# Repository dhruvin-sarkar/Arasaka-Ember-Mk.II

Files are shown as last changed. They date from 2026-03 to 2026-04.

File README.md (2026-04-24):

# Ember Mk.II — Flexible LED Watch

A cyberpunk-inspired wristwatch built on a custom flexible PCB, wrapping high-density alphanumeric LED displays around the wrist in an infinite loop. Displays animated effects and real-time clock output.

---

## What is it?

Ember Mk.II is a handmade wristwatch built around a custom flexible PCB that wraps 14 Broadcom HCMS-2901 alphanumeric LED displays around the wrist.

## How to use it

Press the center button to wake the display and trigger the boot animation. Use the up and down buttons to cycle through menus: time display, mini time, brightness, current, timezone offset, and wave mode. The watch charges and programs over the same 4-pin header used as the wrist. To set the time, send a Unix epoch timestamp over serial.

---

## PCB Layout

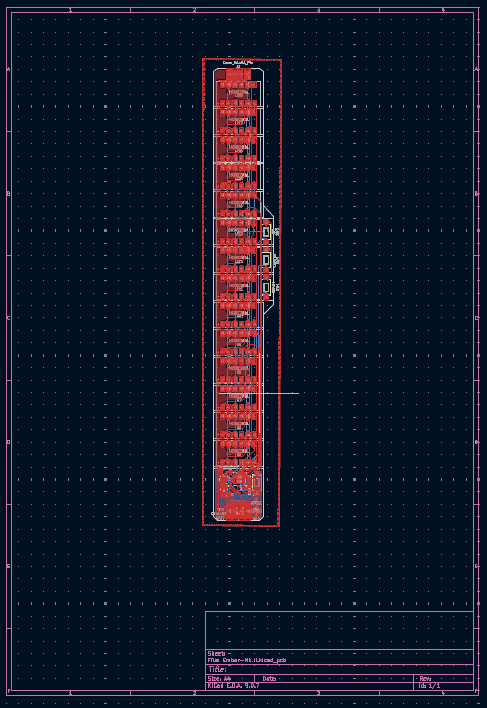
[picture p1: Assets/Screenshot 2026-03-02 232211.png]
PCB Layout


| Top Layer | Bottom Layer | All Layers |
|---|---|---|
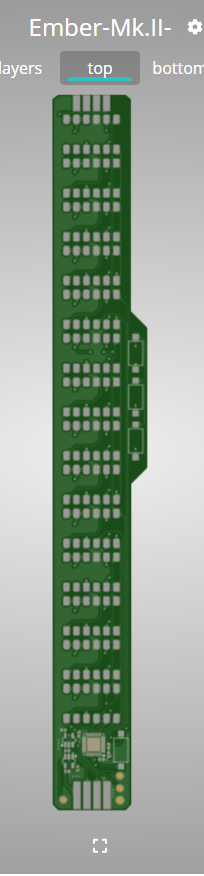
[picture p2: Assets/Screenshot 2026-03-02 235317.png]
Top
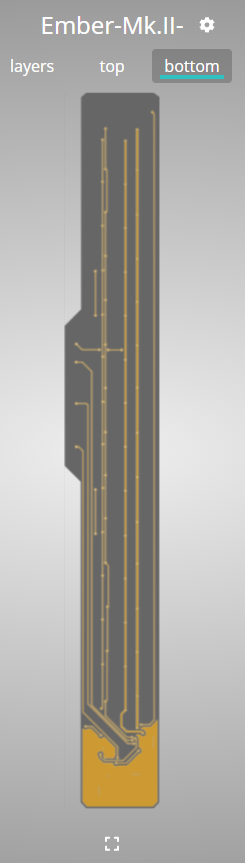
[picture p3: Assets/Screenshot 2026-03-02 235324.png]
Bottom
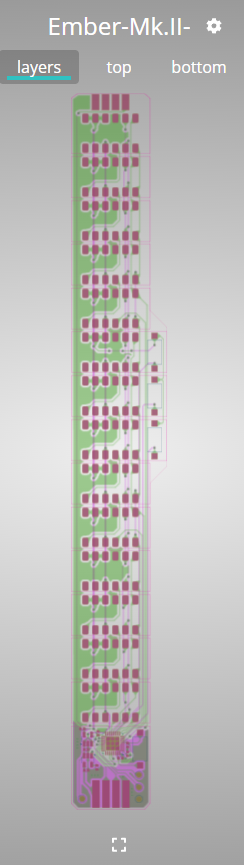
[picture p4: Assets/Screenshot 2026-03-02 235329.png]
Layers
|  |  |  |

---

## Schematic

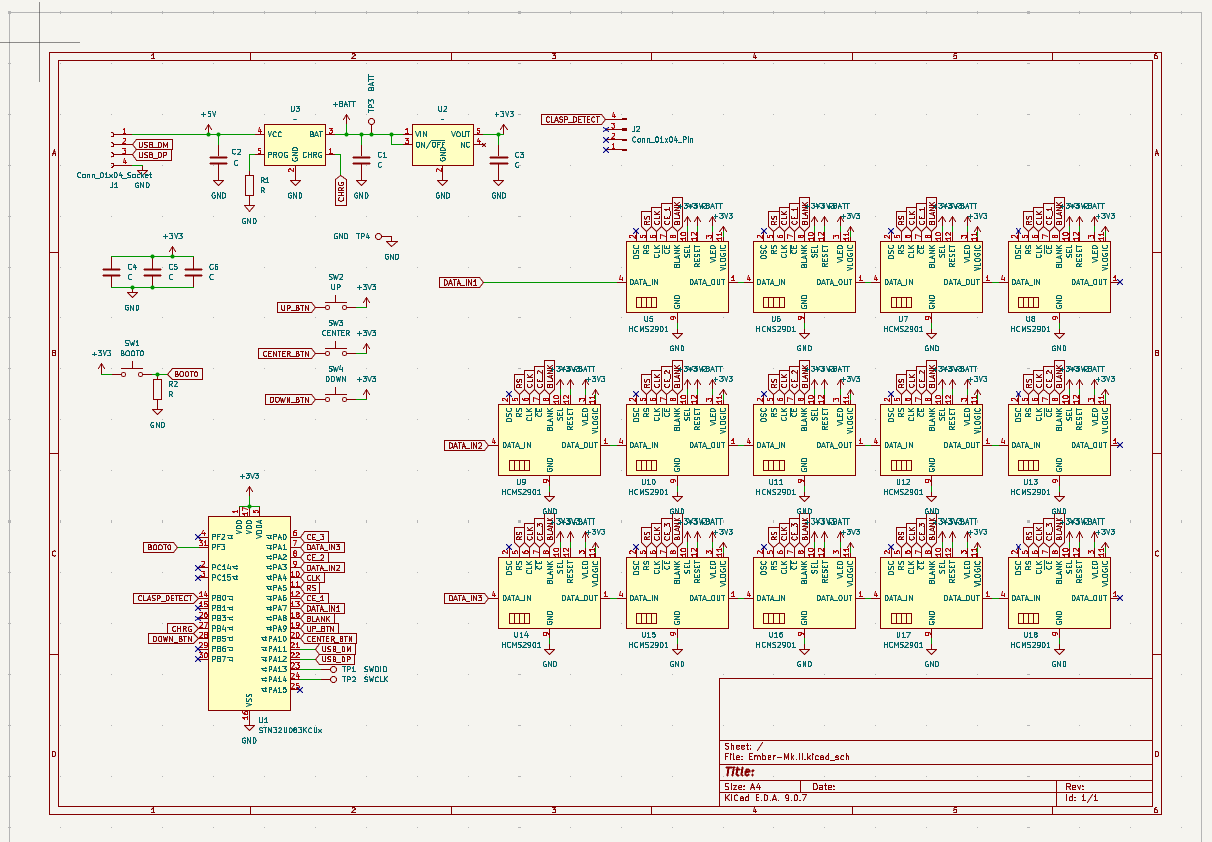
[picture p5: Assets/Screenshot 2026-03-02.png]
Schematic


---

## Bill of Materials

| Ref | Component | Value / Part | Package | Qty | Datasheet / Source |
|-----|---|---|---|-----|---|
| U5–U18 | Alphanumeric LED Display | **HCMS-3901** | Custom SMD (bent TH pins) | 14 | [Broadcom Datasheet](https://docs.broadcom.com/doc/AV02-0683EN) · [Mouser](https://www.mouser.com/ProductDetail/Broadcom-Avago/HCMS-3901) |
| U1 | Microcontroller | **STM32U083KCUx** | QFN-32 | 1 | [ST Datasheet](https://www.st.com/resource/en/datasheet/stm32u083kc.pdf) · [Mouser](https://www.mouser.com/ProductDetail/STMicroelectronics/STM32U083KCU6) |
| U2 | LDO Regulator | **LP2980** (3.3V fixed) | SOT-23-5 | 1 | [TI Datasheet](https://www.ti.com/lit/ds/symlink/lp2980.pdf) · [Mouser](https://www.mouser.com/ProductDetail/Texas-Instruments/LP2980IM5X-3.3) |
| U3 | LiPo Charger | **STC4054** | SOT-23-5 | 1 | [Datasheet](https://datasheet.lcsc.com/lcsc/2210211830_Shenzhen-Fuman-Elec-STC4054_C89852.pdf) · [LCSC](https://www.lcsc.com/product-detail/Battery-Management_Shenzhen-Fuman-Elec-STC4054_C89852.html) |
| J1 | Wrist clasp socket | 4-pin SMD socket | custom:SMD_2.54_1x04_LONG | 1 | Standard 2.54mm pin header |
| J2 | Wrist clasp pin | 4-pin SMD pin | custom:SMD_2.54_1x04_SHORT | 1 | Standard 2.54mm pin header |
| SW1 | Boot mode button | BOOT0 | PTS636 | 1 | [C&K PTS636 Datasheet](https://www.ckswitches.com/media/1471/pts636.pdf) · [Mouser](https://www.mouser.com/ProductDetail/CK/PTS636-SK25-SMTR-LFS) |
| SW2 | Up button | UP | PTS636 | 1 | [C&K PTS636 Datasheet](https://www.ckswitches.com/media/1471/pts636.pdf) |
| SW3 | Center button | CENTER | PTS636 | 1 | [C&K PTS636 Datasheet](https://www.ckswitches.com/media/1471/pts636.pdf) |
| SW4 | Down button | DOWN | PTS636 | 1 | [C&K PTS636 Datasheet](https://www.ckswitches.com/media/1471/pts636.pdf) |
| R1, R2 | Resistor | TBD | 0402 | 2 | Standard 0402 SMD resistor |
| TP1 | Test point | SWDIO | D1.5mm pad | 1 | SWD debug interface |
| TP2 | Test point | SWCLK | D1.5mm pad | 1 | SWD debug interface |
| TP3 | Test point | BATT | D1.5mm pad | 1 | Battery voltage monitor |
| TP4 | Test point | GND | D1.5mm pad | 1 | Ground reference |

> ⚠️ **Display availability note:** The HCMS-2901 is a discontinued Broadcom part. Stock availability varies — check Mouser, DigiKey, and secondary markets. Expect ~$25–35 per unit. The HCMS-3901 is a pin-compatible alternative.

---

## Firmware & Dependencies

Display control is based on a modified version of the HCMS39xx Arduino library:
> https://github.com/Andy4495/HCMS39xx

Modifications include:
- `printDirectBufferOverlay()` — bitwise OR compositing for animation over UI
- `printDirectBufferXOR()` — XOR compositing for blinking effects
- `refreshDisplay()` — decoupled buffer writes from display refresh for frame timing

To compile:
- Install **STM32Duino** (Arduino core for STM32): [https://github.com/stm32duino/Arduino_Core_STM32](https://github.com/stm32duino/Arduino_Core_STM32)
- Install **STM32RTC** library: [https://github.com/stm32duino/STM32RTC](https://github.com/stm32duino/STM32RTC)
- Target board: **STM32U08 series** (Generic STM32U0)

---

## Resources

| Resource | Link |
|---|---|
| STM32U083 Reference Manual | [ST.com](https://www.st.com/resource/en/reference_manual/rm0503-stm32u0-series-advanced-armbased-32bit-mcus-stmicroelectronics.pdf) |
| HCMS-2901 Application Brief | [Broadcom](https://docs.broadcom.com/doc/5988-7539EN) |
| STM32Duino Core | [GitHub](https://github.com/stm32duino/Arduino_Core_STM32) |
| STM32RTC Library | [GitHub](https://github.com/stm32duino/STM32RTC) |
| HCMS39xx Arduino Library (base) | [GitHub](https://github.com/Andy4495/HCMS39xx) |
| KiCad EDA | [kicad.org](https://www.kicad.org) |

---

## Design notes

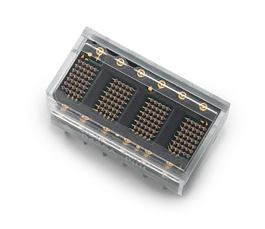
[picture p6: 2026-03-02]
Assets/Screenshot 2026-03-03 001525.png

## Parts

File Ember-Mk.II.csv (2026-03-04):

Reference | Value | Datasheet | Footprint | Qty | DNP
C1,C2,C3,C4,C5,C6 | C | ~ | Capacitor_SMD:C_0402_1005Metric | 6
J1 | Conn_01x04_Socket | ~ | custom:SMD_2.54_1x04_LONG | 1
J2 | Conn_01x04_Pin | ~ | custom:SMD_2.54_1x04_SHORT | 1
R1,R2 | R | ~ | Resistor_SMD:R_0402_1005Metric | 2
SW1 | BOOT0 | ~ | custom:PTS636 | 1
SW2 | UP | ~ | custom:PTS636 | 1
SW3 | CENTER | ~ | custom:PTS636 | 1
SW4 | DOWN | ~ | custom:PTS636 | 1
TP1 | SWDIO | ~ | TestPoint:TestPoint_Pad_D1.5mm | 1
TP2 | SWCLK | ~ | TestPoint:TestPoint_Pad_D1.5mm | 1
TP3 | BATT | ~ | TestPoint:TestPoint_Pad_D1.5mm | 1
TP4 | GND | ~ | TestPoint:TestPoint_Pad_D1.5mm | 1
U1 | STM32U083KCUx | https://www.st.com/resource/en/datasheet/stm32u083kc.pdf | Package_DFN_QFN:QFN-32-1EP_5x5mm_P0.5mm_EP3.45x3.45mm | 1
U2,U3 | ~ |  | Package_TO_SOT_SMD:SOT-23-5 | 2
U5,U6,U7,U8,U9,U10,U11,U12,U13,U14,U15,U16,U17,U18 | HCMS2901 |  | custom:HCMS2901_SMD | 14

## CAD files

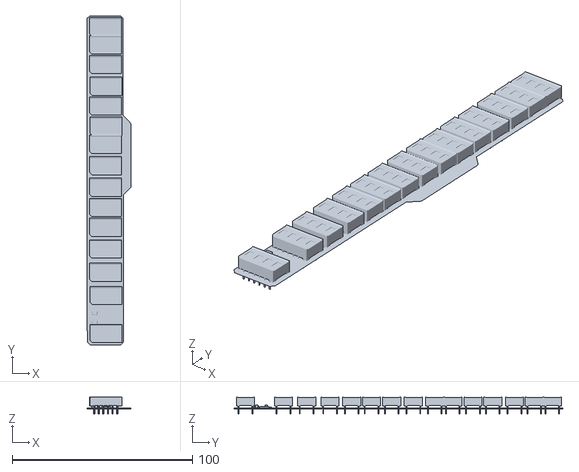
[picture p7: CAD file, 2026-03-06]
Arasaka Mock Render.stl
24.3 x 182.3 x 9.40

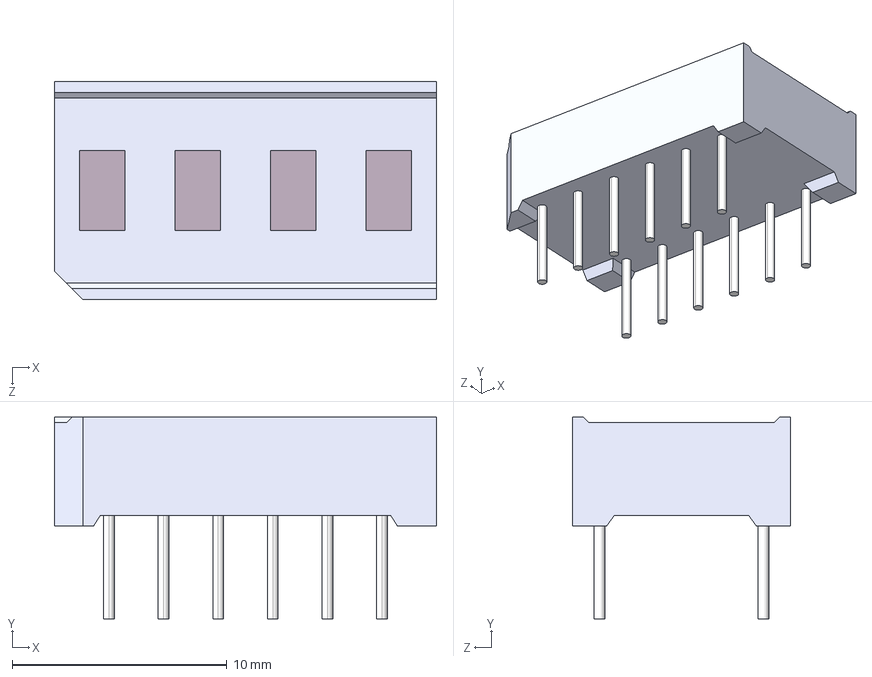
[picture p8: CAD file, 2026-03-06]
HCMS-2901--3DModel-STEP-56544.STEP
17.8 x 9.40 x 10.2 mm

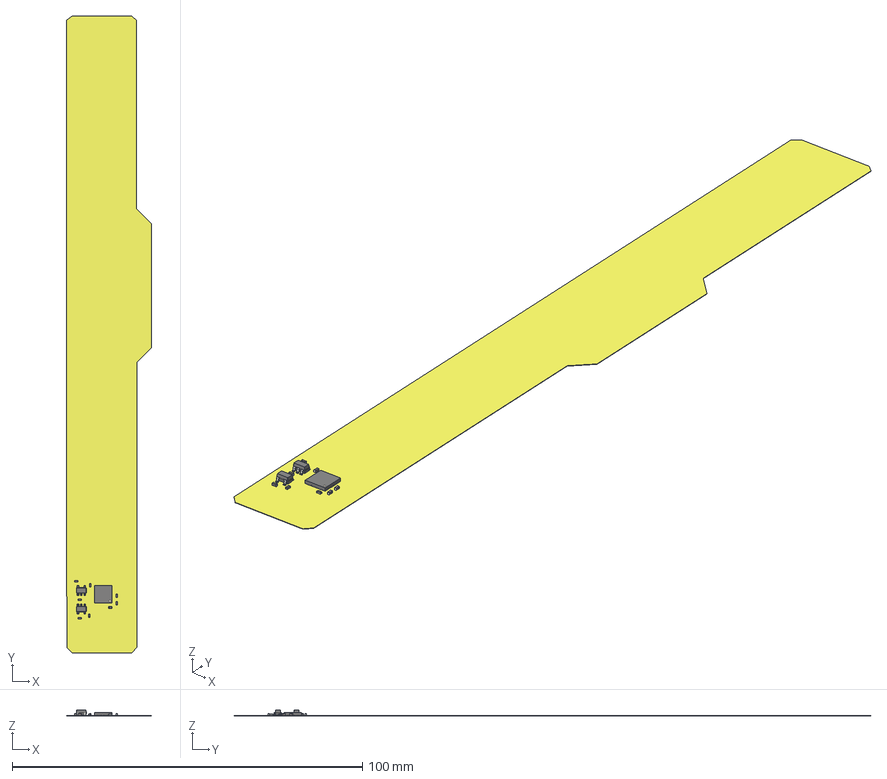
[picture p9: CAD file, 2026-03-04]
Ember-Mk.II.step
24.3 x 181.8 x 1.73 mm
C_0402_1005Metric x 6
SOT-23-5 x 2
QFN-32-1EP_5x5mm_P0.5mm_EP3.45x3.45mm
R_0402_1005Metric x 2
Ember-Mk.II_PCB

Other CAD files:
Ember-Mk.II.stl
HCMS-2901--3DModel-STEP-56544.stl

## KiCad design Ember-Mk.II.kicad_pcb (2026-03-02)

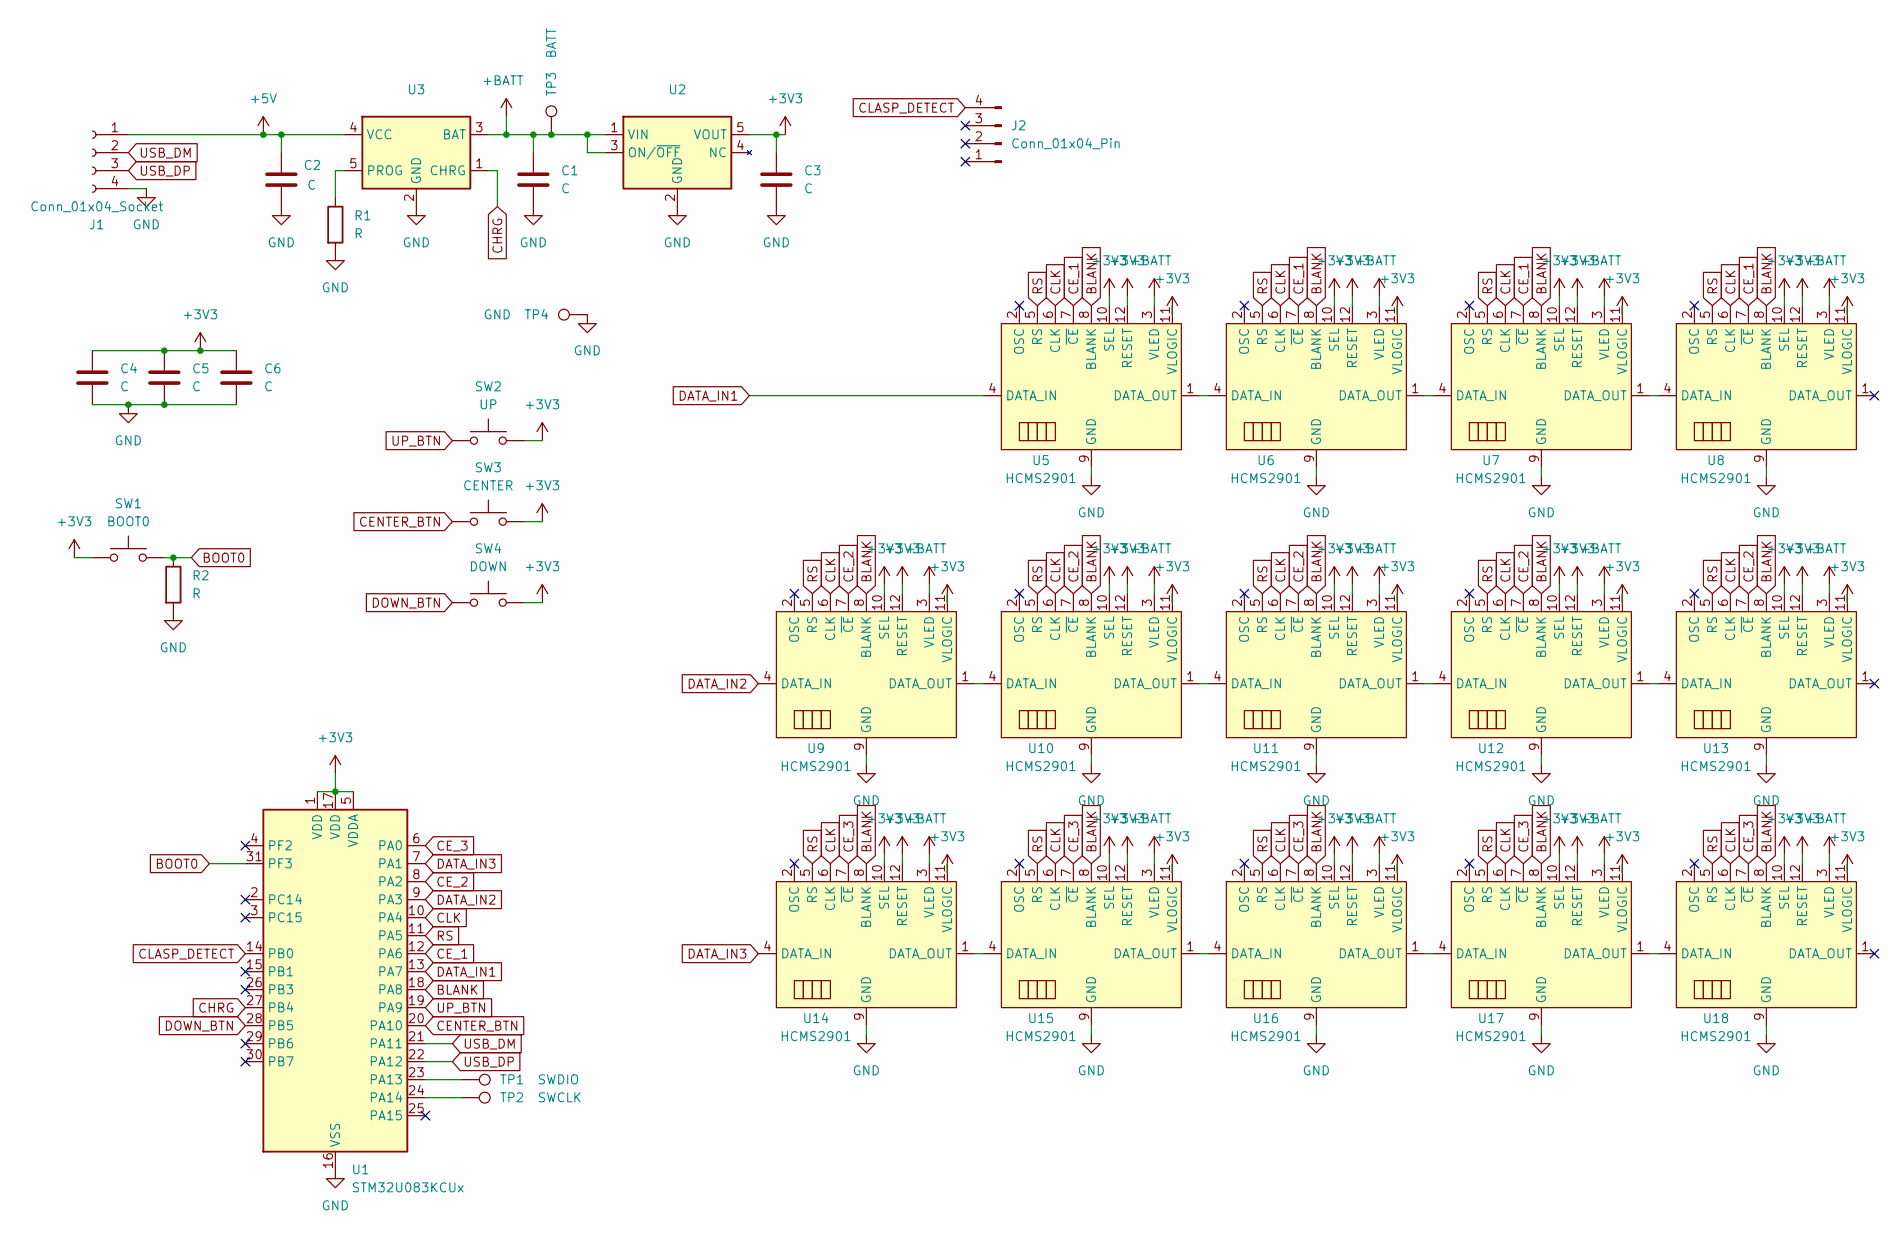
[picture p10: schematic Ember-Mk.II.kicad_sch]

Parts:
C1, C2, C3, C4, C5, C6: C; C_0402_1005Metric
J1: Conn_01x04_Socket; SMD_2.54_1x04_LONG
J2: Conn_01x04_Pin; SMD_2.54_1x04_SHORT
R1, R2: R; R_0402_1005Metric
SW1: BOOT0; PTS636
SW2: UP; PTS636
SW3: CENTER; PTS636
SW4: DOWN; PTS636
TP1: SWDIO; TestPoint_Pad_D1.5mm
TP2: SWCLK; TestPoint_Pad_D1.5mm
TP3: BATT; TestPoint_Pad_D1.5mm
TP4: GND; TestPoint_Pad_D1.5mm
U1: STM32U083KCUx; QFN-32-1EP_5x5mm_P0.5mm_EP3.45x3.45mm
U2, U3: SOT-23-5
U5, U6, U7, U8, U9, U10, U11, U12, U13, U14, U15, U16, U17, U18: HCMS2901; HCMS2901_SMD

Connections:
+3V3: C3.1, C4.1, C5.1, C6.1, SW1.1, SW2.2, SW3.2, SW4.2, U1.1 (VDD), U1.5 (VDDA), U1.17 (VDD), U2.5 (VOUT), U5.10 (SEL), U5.11 (VLOGIC), U5.12 (RESET), U6.10 (SEL), U6.11 (VLOGIC), U6.12 (RESET), U7.10 (SEL), U7.11 (VLOGIC), U7.12 (RESET), U8.10 (SEL), U8.11 (VLOGIC), U8.12 (RESET), U9.10 (SEL), U9.11 (VLOGIC), U9.12 (RESET), U10.10 (SEL), U10.11 (VLOGIC), U10.12 (RESET), U11.10 (SEL), U11.11 (VLOGIC), U11.12 (RESET), U12.10 (SEL), U12.11 (VLOGIC), U12.12 (RESET), U13.10 (SEL), U13.11 (VLOGIC), U13.12 (RESET), U14.10 (SEL), U14.11 (VLOGIC), U14.12 (RESET), U15.10 (SEL), U15.11 (VLOGIC), U15.12 (RESET), U16.10 (SEL), U16.11 (VLOGIC), U16.12 (RESET), U17.10 (SEL), U17.11 (VLOGIC), U17.12 (RESET), U18.10 (SEL), U18.11 (VLOGIC), U18.12 (RESET)
+5V: C2.1, J1.1, U3.4 (VCC)
+BATT: C1.1, TP3.1, U2.1 (VIN), U2.3 (ON/~OFF), U3.3 (BAT), U5.3 (VLED), U6.3 (VLED), U7.3 (VLED), U8.3 (VLED), U9.3 (VLED), U10.3 (VLED), U11.3 (VLED), U12.3 (VLED), U13.3 (VLED), U14.3 (VLED), U15.3 (VLED), U16.3 (VLED), U17.3 (VLED), U18.3 (VLED)
BLANK: U1.18 (PA8), U5.8 (BLANK), U6.8 (BLANK), U7.8 (BLANK), U8.8 (BLANK), U9.8 (BLANK), U10.8 (BLANK), U11.8 (BLANK), U12.8 (BLANK), U13.8 (BLANK), U14.8 (BLANK), U15.8 (BLANK), U16.8 (BLANK), U17.8 (BLANK), U18.8 (BLANK)
BOOT0: R2.1, SW1.2, U1.31 (PF3)
CENTER_BTN: SW3.1, U1.20 (PA10)
CE_1: U1.12 (PA6), U5.7 (~CE), U6.7 (~CE), U7.7 (~CE), U8.7 (~CE)
CE_2: U1.8 (PA2), U9.7 (~CE), U10.7 (~CE), U11.7 (~CE), U12.7 (~CE), U13.7 (~CE)
CE_3: U1.6 (PA0), U14.7 (~CE), U15.7 (~CE), U16.7 (~CE), U17.7 (~CE), U18.7 (~CE)
CHRG: U1.27 (PB4), U3.1 (CHRG)
CLASP_DETECT: J2.4, U1.14 (PB0)
CLK: U1.10 (PA4), U5.6 (CLK), U6.6 (CLK), U7.6 (CLK), U8.6 (CLK), U9.6 (CLK), U10.6 (CLK), U11.6 (CLK), U12.6 (CLK), U13.6 (CLK), U14.6 (CLK), U15.6 (CLK), U16.6 (CLK), U17.6 (CLK), U18.6 (CLK)
DATA_IN1: U1.13 (PA7), U5.4 (DATA_IN)
DATA_IN2: U1.9 (PA3), U9.4 (DATA_IN)
DATA_IN3: U1.7 (PA1), U14.4 (DATA_IN)
DOWN_BTN: SW4.1, U1.28 (PB5)
GND: C1.2, C2.2, C3.2, C4.2, C5.2, C6.2, J1.4, R1.2, R2.2, TP4.1, U1.16 (VSS), U1.32 (VSS), U1.33 (VSS), U2.2 (GND), U3.2 (GND), U5.9 (GND), U6.9 (GND), U7.9 (GND), U8.9 (GND), U9.9 (GND), U10.9 (GND), U11.9 (GND), U12.9 (GND), U13.9 (GND), U14.9 (GND), U15.9 (GND), U16.9 (GND), U17.9 (GND), U18.9 (GND)
unnamed: TP1.1, U1.23 (PA13)
unnamed: TP2.1, U1.24 (PA14)
unnamed: R1.1, U3.5 (PROG)
unnamed: U5.1 (DATA_OUT), U6.4 (DATA_IN)
unnamed: U6.1 (DATA_OUT), U7.4 (DATA_IN)
unnamed: U7.1 (DATA_OUT), U8.4 (DATA_IN)
unnamed: U9.1 (DATA_OUT), U10.4 (DATA_IN)
unnamed: U10.1 (DATA_OUT), U11.4 (DATA_IN)
unnamed: U11.1 (DATA_OUT), U12.4 (DATA_IN)
unnamed: U12.1 (DATA_OUT), U13.4 (DATA_IN)
unnamed: U14.1 (DATA_OUT), U15.4 (DATA_IN)
unnamed: U15.1 (DATA_OUT), U16.4 (DATA_IN)
unnamed: U16.1 (DATA_OUT), U17.4 (DATA_IN)
unnamed: U17.1 (DATA_OUT), U18.4 (DATA_IN)
RS: U1.11 (PA5), U5.5 (RS), U6.5 (RS), U7.5 (RS), U8.5 (RS), U9.5 (RS), U10.5 (RS), U11.5 (RS), U12.5 (RS), U13.5 (RS), U14.5 (RS), U15.5 (RS), U16.5 (RS), U17.5 (RS), U18.5 (RS)
UP_BTN: SW2.1, U1.19 (PA9)
USB_DM: J1.2, U1.21 (PA11)
USB_DP: J1.3, U1.22 (PA12)

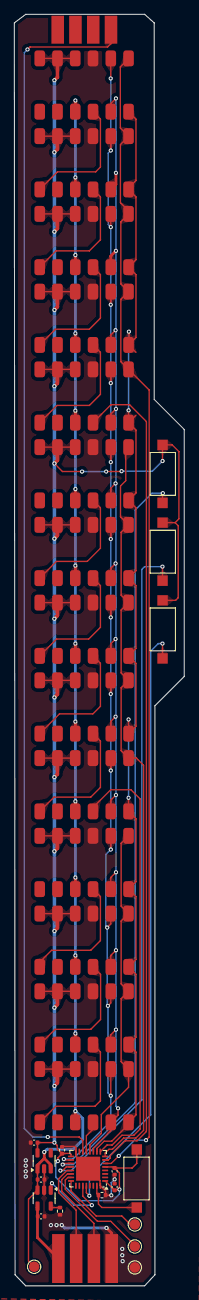
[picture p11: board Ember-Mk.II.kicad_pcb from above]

Board: 2 copper layers, 24.3 x 181.8 mm, 35 parts (0 on the bottom side), 35 nets.

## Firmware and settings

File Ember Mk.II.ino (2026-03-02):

#include "HCMS39xx.h"
#include "font5x7.h"
#include <STM32RTC.h>

STM32RTC& rtc = STM32RTC::getInstance();

// HCMS39xx(uint8_t num_chars, uint8_t data_pin, uint8_t rs_pin, uint8_t clk_pin, uint8_t ce_pin, uint8_t blank_pin)
HCMS39xx myDisplay1(16, PA7, PA5, PA4, PA6, PA8); // osc_select_pin tied high
HCMS39xx myDisplay2(20, PA3, PA5, PA4, PA2, PA8); // osc_select_pin tied high
HCMS39xx myDisplay3(20, PA1, PA5, PA4, PA0, PA8); // osc_select_pin tied high

#define MAXLEN 4
#define UP_BTN PA9
#define CENTER_BTN PA10
#define DOWN_BTN PB5
#define CHRG_DETECT PB4
#define CLASP_DETECT PB0

uint8_t testGrid[280];
uint8_t daylight_savings = 1;
uint8_t animation_buffer[280];
uint8_t colon_layer_buffer[280];
uint32_t loop_start = 0;
uint32_t loop_stop = 0;
uint32_t delta_time = 0;
uint32_t delta_accumulator = 0;
uint32_t animation_frame = 0;
uint32_t number= 1700;
int8_t current_timezone_offset = 0;
uint8_t selected_animation = 0;

bool HAS_BEEN = 0;

int hour;
int minute;
int second;
int day_of_week;
int year;
int month;
int day;
int year_day;

const char* day_strings[] = {"D SN", "D MN", "D TU", "D WE", "D TH", "D FR", "D SA"};


enum Menu {show_mini_time, show_home, show_time, set_brightness, set_current, set_time_zone_offset, wave_mode, NUM_STATES};
Menu current_menu = show_home;


HCMS39xx::DISPLAY_CURRENT current_options[] = {
  HCMS39xx::CURRENT_12_8_mA,
  HCMS39xx::CURRENT_4_0_mA,
  HCMS39xx::CURRENT_6_4_mA,
  HCMS39xx::CURRENT_9_3_mA,
};

HCMS39xx::DISPLAY_CURRENT current_current = HCMS39xx::DEFAULT_CURRENT;

const int num_current_options = sizeof(current_options)/sizeof(current_options[0]);
int current_index = 0;

void increaseCurrent() {
  current_index = (current_index + 1) % num_current_options;
  current_current = current_options[current_index];
}

void decreaseCurrent() {
  current_index = (current_index + num_current_options - 1) % num_current_options;
  current_current = current_options[current_index];
}

bool show_text = false;
uint8_t current_brightness = 15;

bool lastUPButtonState = true; // Default high to prevent startup animation
bool lastDOWNButtonState = true;
bool lastCENTERButtonState = true;
bool UPButtonState = false;
bool DOWNButtonState = false;
bool CENTERButtonState = false;

bool menu_engaged = false;

void setup() {
  pinMode(UP_BTN, INPUT_PULLDOWN);
  pinMode(CENTER_BTN, INPUT_PULLDOWN);
  pinMode(DOWN_BTN, INPUT_PULLDOWN);
  pinMode(CHRG_DETECT, INPUT_PULLUP);
  pinMode(CLASP_DETECT, INPUT_PULLUP);

  for (uint32_t i = 0; i < 280; i++) {
    testGrid[i] = 0b11111111;
  }
  
  colon_layer_buffer[110] = 0b00100100;
  
  Serial.begin(115200);

  myDisplay1.begin();
  myDisplay1.displayUnblank();
  myDisplay1.setSerialMode();
  myDisplay1.setBrightness(current_brightness);
  myDisplay1.setCurrent(current_current);

  myDisplay2.begin();
  myDisplay2.displayUnblank();
  myDisplay2.setSerialMode();
  myDisplay2.setBrightness(current_brightness);
  myDisplay2.setCurrent(current_current);

  myDisplay3.begin();
  myDisplay3.displayUnblank();
  myDisplay3.setSerialMode();
  myDisplay3.setBrightness(current_brightness);
  myDisplay3.setCurrent(current_current);

  //initialise time
  rtc.begin(0);
  if (!rtc.isTimeSet()) {
    uint32_t unixTime = 1752700800UL; // 17 Jul 2025 00:00:00 UTC
    rtc.setEpoch(unixTime);
  }

  delay(500);
}

void loop() {
  loop_start = micros();
  
  //myDisplay1.begin();
  //myDisplay1.displayUnblank();
  //myDisplay1.setSerialMode();
  //myDisplay1.setBrightness(current_brightness);
  //myDisplay1.setCurrent(current_current);

  //myDisplay2.begin();
  //myDisplay2.displayUnblank();
  //myDisplay2.setSerialMode();
  //myDisplay2.setBrightness(current_brightness);
  //myDisplay2.setCurrent(current_current);

  //myDisplay3.begin();
  //myDisplay3.displayUnblank();
  //myDisplay3.setSerialMode();
  //myDisplay3.setBrightness(current_brightness);
  //myDisplay3.setCurrent(current_current);
  

  UPButtonState = digitalRead(UP_BTN);
  DOWNButtonState = digitalRead(DOWN_BTN);
  CENTERButtonState = digitalRead(CENTER_BTN);

  //Serial.println(digitalRead(CHRG_DETECT));
  //Serial.println(digitalRead(CLASP_DETECT));

  if (Serial.available()) {
    // Read the incoming string until newline
    String input = Serial.readStringUntil('\n');
    input.trim(); // Remove any trailing \r or whitespace

    if (input == "bootloader") {
      enterBootloader();  // jump to DFU
    } else if (input == "reset") {
      NVIC_SystemReset(); // core reset
    } else {
      // Otherwise, treat it as an epoch time
      time_t newTime = (time_t)input.toInt() + (current_timezone_offset * 3600);
      rtc.setEpoch(newTime);

      Serial.print("Time set to: ");
      Serial.println(newTime);
    }
  }
  uint32_t now = rtc.getEpoch();
  time_t t = now;
  struct tm* tmstruct = localtime(&t);

  hour = tmstruct->tm_hour;
  minute = tmstruct->tm_min;
  second = tmstruct->tm_sec;
  day_of_week = tmstruct->tm_wday;
  year = tmstruct->tm_year + 1900; // <- Fix: convert to full year
  month = tmstruct->tm_mon + 1;    // <- Fix: human-friendly month
  day = tmstruct->tm_mday;
  year_day = tmstruct->tm_yday;

  

  myDisplay1.clear();
  myDisplay2.clear();
  myDisplay3.clear();

  if (CENTERButtonState && !lastCENTERButtonState && animation_frame==0 && !menu_engaged) {
    ;
  } else if (UPButtonState && !lastUPButtonState && !menu_engaged) {
    current_menu = static_cast<Menu>((current_menu + 1) % NUM_STATES);
    clear_animation_buffer();
    animation_frame = 0;
  } else if (DOWNButtonState && !lastDOWNButtonState && !menu_engaged) {
    current_menu = static_cast<Menu>((current_menu + NUM_STATES - 1) % NUM_STATES);
    clear_animation_buffer();
    animation_frame = 0;
  }

  switch (current_menu) {
    case show_mini_time:
      display_show_minitime();
      break;
    case show_home:
      display_show_home();
      break;
    case show_time:
      display_show_time();
      break;
    case set_brightness:
      display_set_brightness();
      break;
    case set_current:
      display_set_current();
      break;
    case set_time_zone_offset:
      display_set_time_zone_offset();
      break;
    case wave_mode:
      display_wave_mode();
      break;
  }

  if (!digitalRead(CHRG_DETECT)) {
    myDisplay1.print("            CHRG");
  }
  //Serial.println(HAS_BEEN);
  
  
  myDisplay1.printDirectBufferOverlay(&animation_buffer[200], 80);
  myDisplay2.printDirectBufferOverlay(&animation_buffer[100], 100);
  myDisplay3.printDirectBufferOverlay(&animation_buffer[0], 100);
  //myDisplay1.printDirectBufferOverlay(&testGrid[200], 80);
  //myDisplay2.printDirectBufferOverlay(&testGrid[100], 100);
  //myDisplay3.printDirectBufferOverlay(&testGrid[0], 100);

  myDisplay1.refreshDisplay();
  myDisplay2.refreshDisplay();
  myDisplay3.refreshDisplay();
  
  
  if (animation_frame>0){
  if(delta_accumulator >= 25000 || animation_frame==1) { // If more than 33ms has passed or animation is just started
    delta_accumulator = 0;
    if (animation_frame>0) {
      animation_frame++;
      switch (selected_animation) {
        case 0:
          renderWaterfallFrame2();
          if (animation_frame == 90){
            showText(true);
          }
          finish_at_frame(300);
          break;
        case 1:
          renderWaterfallFrame3();
          finish_at_frame(300);
          break;
        break;
      }
      
      

    }

  } else {
    delta_accumulator += delta_time;
  }
  }

  
  
  

  lastUPButtonState = UPButtonState;
  lastDOWNButtonState = DOWNButtonState;
  lastCENTERButtonState = CENTERButtonState;
  loop_stop = micros();
  delta_time = loop_stop-loop_start;
  //delay(500);
}

void startAnimation(uint8_t animation){
  animation_frame = 1;
  selected_animation = animation;
}

void finish_at_frame(uint32_t last_frame) {
  if (animation_frame >= last_frame) {
    animation_frame = 0;
    showText(false);
  }
}

void renderWaterfallFrame2() {
  if (animation_frame > 0) {

    for (int display_number=0; display_number<14; display_number++) { // For all displays
      shiftDown(&animation_buffer[(display_number*20)]); // Shift down pixels on all displays
    }
    for (int display_number=0; display_number<14; display_number++) { // For all displays
      carryPixelsOver(&animation_buffer[(display_number*20)], &animation_buffer[(display_number*20)+20]); // Carry pixels over from bottom of one display to the top of another
    }

    // For the first display
    for (int i = 0; i < 3; i++) { // For every character
      for (int ii = 0; ii < 20; ii++) { // For every column in a display
        animation_buffer[ii] |= 0b00000001;
          if (animation_frame < 30 ) { // Frames <30
            if (random(40) > animation_frame ) {  // Chance to remove drop
              animation_buffer[ii] ^= 0b00000001;
            }
          } else {
            if (random(40) < -(30 - animation_frame) ) {  // Chance to remove drop
              animation_buffer[ii] ^= 0b00000001;
            }
          }
      }
    }

  }
}

void renderWaterfallFrame3() {
  if (animation_frame > 0) {

    for (int display_number=0; display_number<14; display_number++) { // For all displays
      shiftDown(&animation_buffer[(display_number*20)]); // Shift down pixels on all displays
    }
    for (int display_number=0; display_number<14; display_number++) { // For all displays
      if (display_number != 4){
        carryPixelsOver(&animation_buffer[(display_number*20)], &animation_buffer[(display_number*20)+20]); // Carry pixels over from bottom of one display to the top of another
      } else {
        carryPixelsOver(&animation_buffer[(display_number*20)], &animation_buffer[((display_number+3)*20)+20]); // Carry pixels over from bottom of one display to the top of another
      }
    }

    // For the first display
    for (int i = 0; i < 3; i++) { // For every character
      for (int ii = 0; ii < 20; ii++) { // For every column in a display
        animation_buffer[ii] |= 0b00000001;
        if (random(100) < 75 ) {  // Chance to remove drop
          animation_buffer[ii] ^= 0b00000001;
        }
            
      }
    }
    memset(&animation_buffer[100], 0, 60);
  }
}

void showText(bool show){
  if (show) {
    show_text = true;
  } else {
    show_text = false;
  }
}

void carryPixelsOver(uint8_t* source, uint8_t* dest){
  for(int i=0; i<20; i++){
    dest[i] |= (source[i] & 0b10000000) >> 7; // place carry into LSB of byte2
  }
}

void shiftDown(uint8_t* source){
  for(int i=0; i<20; i++){
    source[i] <<= 1; // place carry into LSB of byte2
  }
}


void enterBootloader() {
  void (*SysMemBootJump)(void);
  uint32_t bootloaderAddr = 0x1FFF0000;  // STM32U083 system memory start

  // De-initialize peripherals (especially USB if active)
  Serial.end();         // if Serial is over USB
  //USBDevice.detach();   // detach USB to allow bootloader to re-enumerate

  delay(100);  // Give host time to process USB detach

  __disable_irq();  // Disable all interrupts

  // Set stack pointer and jump to system memory reset handler
  __set_MSP(*(uint32_t *)bootloaderAddr);
  SysMemBootJump = (void (*)(void)) (*((uint32_t *)(bootloaderAddr + 4)));
  SysMemBootJump();
}

void display_show_minitime(){
  char buffertimeMini[21]; // With extra for null terminator
      snprintf(buffertimeMini, sizeof(buffertimeMini), "    %02d%02d", hour+daylight_savings, minute);
      myDisplay2.print(buffertimeMini);
      
      if(delta_accumulator < 1000000) { // If more than 33ms has passed or animation is just started
        if (delta_accumulator > 500000) {
          myDisplay2.printDirectBufferXOR(&colon_layer_buffer[80], 100);

        } else {
          
        }
        delta_accumulator += delta_time;
      } else {
        delta_accumulator = 0;
      }
}

void display_show_home(){
  
      if (CENTERButtonState && !lastCENTERButtonState) {
        startAnimation(0);
      }
      if (show_text) {
        myDisplay1.print("                ");
        char buffer[21]; // With extra for null terminator
        snprintf(buffer, sizeof(buffer), "H %02dM %02dS %02d", hour+daylight_savings, minute, second);
        myDisplay2.print(buffer);
        myDisplay3.print("                    ");
      }
      //Serial.println("show home");
}

void display_show_time(){
  
      //myDisplay1.print("                ");
      char buffertime3[21]; // With extra for null terminator
      snprintf(buffertime3, sizeof(buffertime3), "H %02dM %02dS %02dD %02dY %02d", hour, minute, second, day, year-2000);
      myDisplay3.print(buffertime3);
      char buffertime2[21];
      snprintf(buffertime2, sizeof(buffertime2), "M %02dD %02dH %02dM %02dS %02d", month, day, hour+daylight_savings, minute, second);
      myDisplay2.print(buffertime2);
      char buffertime1[17];
      snprintf(buffertime1, sizeof(buffertime1), "%sH %02dM %02dS %02d", day_strings[day_of_week], hour, minute, second);
      myDisplay1.print(buffertime1);
      //Serial.println("show time");
}

void display_set_brightness(){
  if (CENTERButtonState && !lastCENTERButtonState) {
        if (menu_engaged) {
          menu_engaged = false;
        } else{
          menu_engaged = true;
        }
      }
      if (menu_engaged) {
      if (UPButtonState && !lastUPButtonState) {
        if(current_brightness+1!=16){
          current_brightness++;
        }
        myDisplay1.setBrightness(current_brightness);
        myDisplay2.setBrightness(current_brightness);
        myDisplay3.setBrightness(current_brightness);
      } else if (DOWNButtonState && !lastDOWNButtonState) {
        if(current_brightness-1!=0){
          current_brightness--;
        }
        myDisplay1.setBrightness(current_brightness);
        myDisplay2.setBrightness(current_brightness);
        myDisplay3.setBrightness(current_brightness);
      }
      }

      myDisplay1.print("                ");
      char bufferbright[21]; // With extra for null terminator
      snprintf(bufferbright, sizeof(bufferbright), "        SET GLOW- %02d", current_brightness);
      myDisplay2.print(bufferbright);
      myDisplay3.print("                    ");
      //Serial.println("set brightness");
}

void display_set_current(){
  if (CENTERButtonState && !lastCENTERButtonState) {
        if (menu_engaged) {
          menu_engaged = false;
        } else{
          menu_engaged = true;
        }
      }
      if (menu_engaged) {
      if (UPButtonState && !lastUPButtonState) {
        if(current_current+1!=16){
          increaseCurrent();
        }
        myDisplay1.setCurrent(current_current);
        myDisplay2.setCurrent(current_current);
        myDisplay3.setCurrent(current_current);
      } else if (DOWNButtonState && !lastDOWNButtonState) {
        if(current_current-1!=0){
          decreaseCurrent();;
        }
        myDisplay1.setCurrent(current_current);
        myDisplay2.setCurrent(current_current);
        myDisplay3.setCurrent(current_current);
      }
      }
      
      myDisplay1.print("                ");
      char bufferCurr[21]; // With extra for null terminator
      const char* current_current_display;
      if (current_current == 48) {
        current_current_display = "12.8";
      } else if (current_current == 32) {
        current_current_display = " 4.0";
      } else if (current_current == 16) {
        current_current_display = " 6.4";
      } else if (current_current == 0) {
        current_current_display = " 9.3";
      } else {
        current_current_display = "UNDF";
      }
      
      snprintf(bufferCurr, sizeof(bufferCurr), "        SET mAMP%s", current_current_display);
      myDisplay2.print(bufferCurr);
      myDisplay3.print("                    ");
      //Serial.println("set current");
}

void display_set_time_zone_offset(){
  if (CENTERButtonState && !lastCENTERButtonState) {
        if (menu_engaged) {
          menu_engaged = false;
        } else{
          menu_engaged = true;
        }
      }
      if (menu_engaged) {
      if (UPButtonState && !lastUPButtonState) {
        if(current_timezone_offset+1!=24){
          current_timezone_offset ++;
          rtc.setEpoch(rtc.getEpoch()+3600);
        }
        
        
      } else if (DOWNButtonState && !lastDOWNButtonState) {
        if(current_current-1!=-24){
          current_timezone_offset --;
          rtc.setEpoch(rtc.getEpoch()-3600);
        }
        
      }
      }
      
      myDisplay1.print("                ");
      char bufferTimezone[21]; // With extra for null terminator
      
      snprintf(bufferTimezone, sizeof(bufferTimezone), "        SET ZONE%02d", current_timezone_offset);
      myDisplay2.print(bufferTimezone);
      myDisplay3.print("                    ");
}

void display_wave_mode(){
  if (animation_frame == 0) {
        startAnimation(1);
      }
      myDisplay1.print("                ");
      char bufferwave[21]; // With extra for null terminator
      snprintf(bufferwave, sizeof(bufferwave), "H %02dM %02dS %02d", hour+daylight_savings, minute, second);
      myDisplay2.print(bufferwave);
      myDisplay3.print("                    ");
      
      //Serial.println("show home");
}

void clear_animation_buffer(){
  memset(animation_buffer, 0, 280);
}

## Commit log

2026-03-02 Revise README with project scope and firmware info
    Updated project description and details for the flexible LED watch.
2026-03-02 Ember Firmware for the STM32Duino, this was written for the STM32U08
2026-03-02 Add custom schematic symbol library defines schematic symbols for parts not in standard KiCad libraries (e.g. your STM32U083, display modules)
2026-03-02 Add main schematic for Ember Mk.II. The full circuit diagram: MCU, charging circuit, display connections, buttons, power rails.
    [Ember-Mk.II.kicad_sch]
2026-03-02 he PCB layout file — the actual flexible board design, component placement, copper traces, stiffener regions.
    [Ember-Mk.II.kicad_pcb]
2026-03-02 The KiCad project file — ties the schematic and PCB together, stores project-level settings.
2026-03-02 Local project settings — stores UI state like which layers are visible, zoom level.
2026-03-02 ibrary lookup table — tells KiCad where to find your symbol libraries (including custom.kicad_sym).
2026-03-02 Custom KiCad footprint library — contains .kicad_mod files for your non-standard components (like your bent through-hole displays used as SMD).
2026-03-02 Adding all screenshots of the schematics and pcb
2026-03-02 Enhance README with project details and design considerations
    Added a section detailing how the system works, including information about the LED displays, power management, and PCB design considerations. Updated key design considerations for clarity and added 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
2026-03-04 Bill Of Materials.csv
    [Ember-Mk.II.csv]
2026-03-04 .STEP file
    [Ember-Mk.II.step]
2026-03-06 3D models?
    [Arasaka Mock Render.stl, Ember-Mk.II.stl, HCMS-2901--3DModel-STEP-56544.STEP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]
